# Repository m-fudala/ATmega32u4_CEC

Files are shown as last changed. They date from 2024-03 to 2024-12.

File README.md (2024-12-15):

# ATmega32U4 CEC device
## Software
HDMI CEC protocol has been programmed using GPIO pins and timers.\
Full protocol feature set is to be done (address setting, commands etc.).&nbsp;&nbsp;

Sample message sent and received:

Message captured

## Hardware
PCB has been designed as a pass-through between media player and a TV. Arduino Pro Micro is used as the brains of the device.
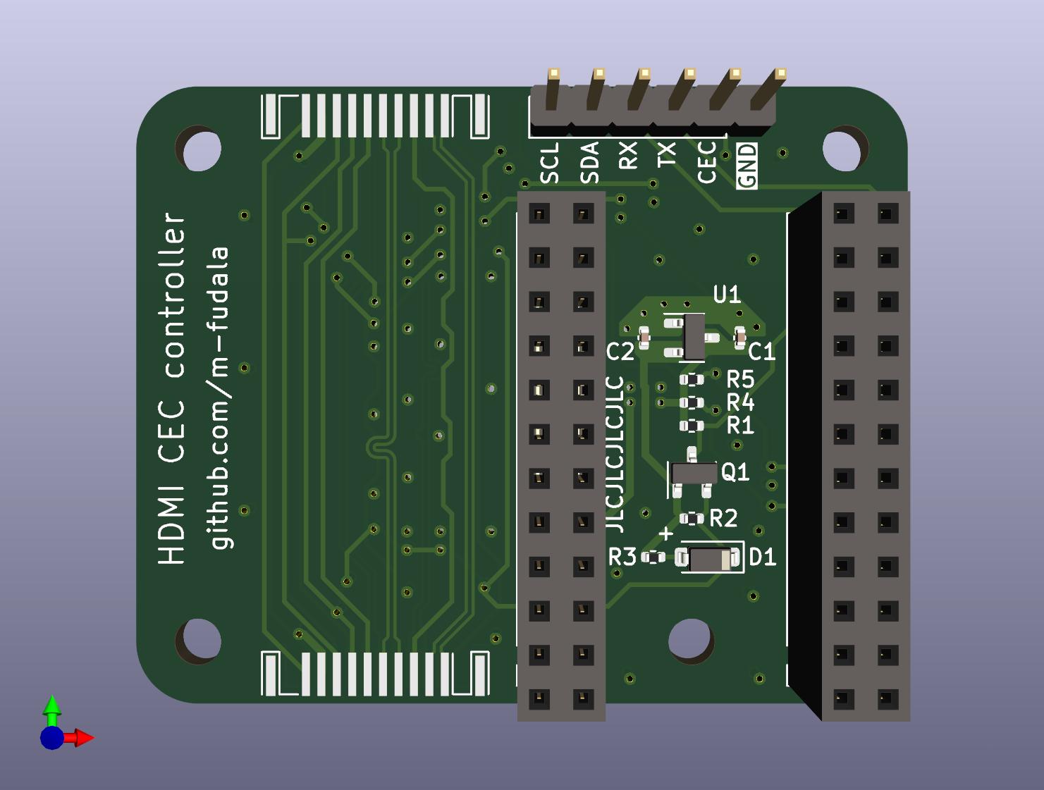
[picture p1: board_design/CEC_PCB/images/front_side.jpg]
Front side of the PCB
\
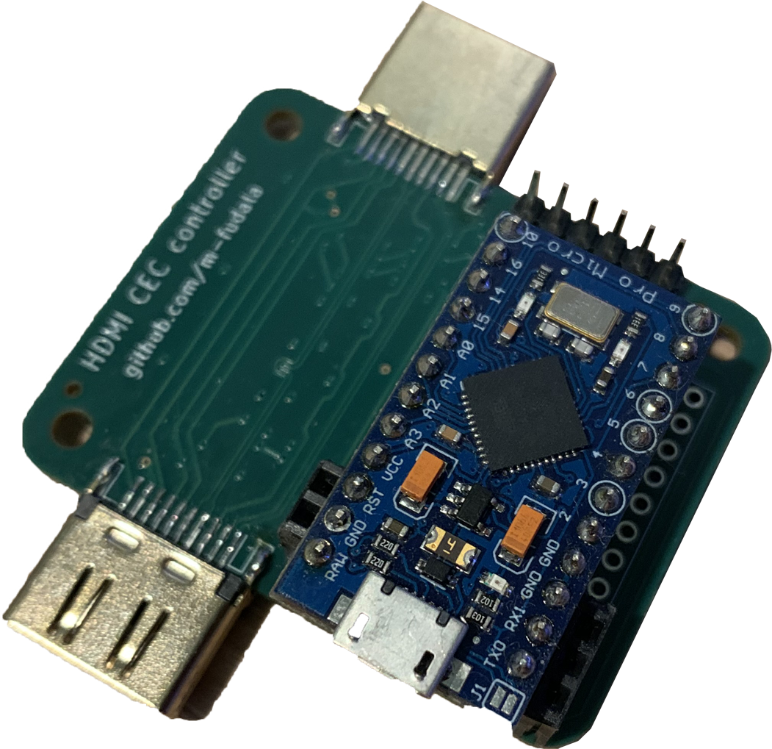
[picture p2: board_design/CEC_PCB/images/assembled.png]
Assembled PCB


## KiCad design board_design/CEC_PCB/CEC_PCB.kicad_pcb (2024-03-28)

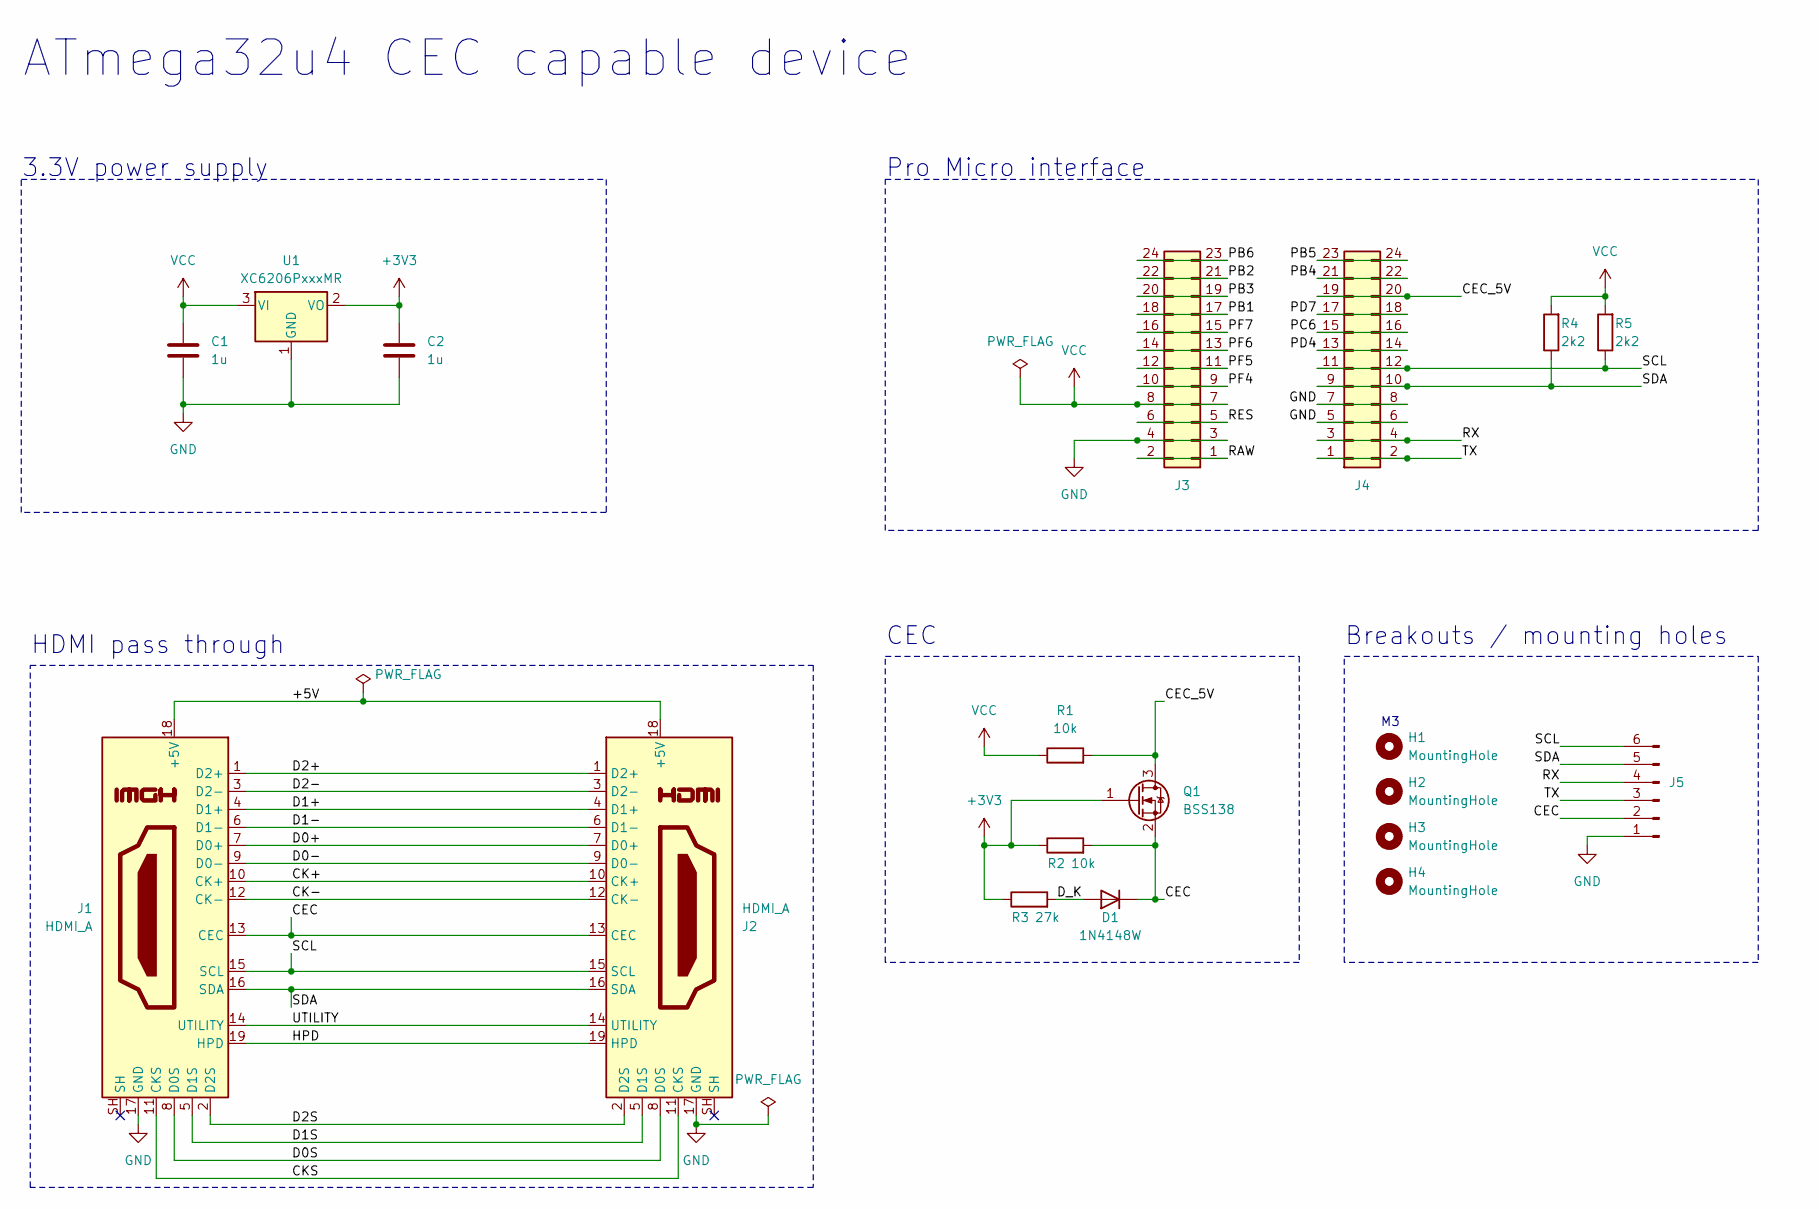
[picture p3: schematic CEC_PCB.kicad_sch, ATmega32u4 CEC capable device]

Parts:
C1, C2: 1u; C_0402_1005Metric
D1: 1N4148W; D_SOD-123
H1, H2, H3, H4: MountingHole; MountingHole_3mm
J1, J2: HDMI_A; HDMI_A_Contact_Technology_HDMI-19APL2_Horizontal
J3, J4: Conn_02x12_Odd_Even; PinSocket_2x12_P2.54mm_Vertical
J5: Conn_01x06_Pin; PinHeader_1x06_P2.54mm_Vertical
Q1: BSS138; SOT-23
R1, R2: 10k; R_0402_1005Metric
R3: 27k; R_0402_1005Metric
R4, R5: 2k2; R_0402_1005Metric
U1: XC6206PxxxMR; SOT-23-3

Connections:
+3V3: C2.1, Q1.1 (G), R2.1, R3.1, U1.2 (VO)
/+5V: J1.18 (+5V), J2.18 (+5V)
/CEC: D1.1 (K), J1.13 (CEC), J2.13 (CEC), J5.2, Q1.2 (S), R2.2
/CEC_5V: J3.19, J3.20, Q1.3 (D), R1.2
/CK+: J1.10 (CK+), J2.10 (CK+)
/CK-: J1.12 (CK-), J2.12 (CK-)
/CKS: J1.11 (CKS), J2.11 (CKS)
/D0+: J1.7 (D0+), J2.7 (D0+)
/D0-: J1.9 (D0-), J2.9 (D0-)
/D0S: J1.8 (D0S), J2.8 (D0S)
/D1+: J1.4 (D1+), J2.4 (D1+)
/D1-: J1.6 (D1-), J2.6 (D1-)
/D1S: J1.5 (D1S), J2.5 (D1S)
/D2+: J1.1 (D2+), J2.1 (D2+)
/D2-: J1.3 (D2-), J2.3 (D2-)
/D2S: J1.2 (D2S), J2.2 (D2S)
/D_K: D1.2 (A), R3.2
/HPD: J1.19 (HPD), J2.19 (HPD)
/PB1: J4.17, J4.18
/PB2: J4.21, J4.22
/PB3: J4.19, J4.20
/PB4: J3.21, J3.22
/PB5: J3.23, J3.24
/PB6: J4.23, J4.24
/PC6: J3.15, J3.16
/PD4: J3.13, J3.14
/PD7: J3.17, J3.18
/PF4: J4.9, J4.10
/PF5: J4.11, J4.12
/PF6: J4.13, J4.14
/PF7: J4.15, J4.16
/RAW: J4.1, J4.2
/RES: J4.5, J4.6
/RX: J3.3, J3.4, J5.4
/SCL: J1.15 (SCL), J2.15 (SCL), J3.11, J3.12, J5.6, R5.1
/SDA: J1.16 (SDA), J2.16 (SDA), J3.9, J3.10, J5.5, R4.1
/TX: J3.1, J3.2, J5.3
/UTILITY: J1.14 (UTILITY), J2.14 (UTILITY)
GND: C1.2, C2.2, J1.17 (GND), J2.17 (GND), J3.5, J3.6, J3.7, J3.8, J4.3, J4.4, J5.1, U1.1 (GND)
VCC: C1.1, J4.7, J4.8, R1.1, R4.2, R5.2, U1.3 (VI)

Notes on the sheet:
Breakouts / mounting holes
CEC
HDMI pass through
Pro Micro interface
ATmega32u4 CEC capable device
3.3V power supply

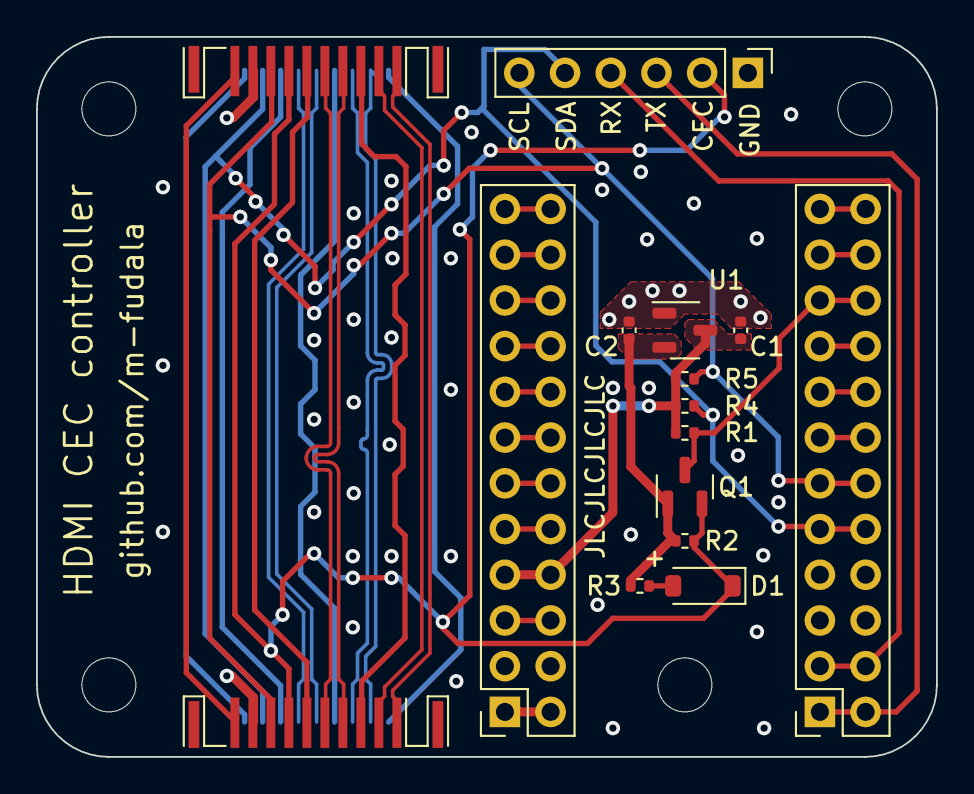
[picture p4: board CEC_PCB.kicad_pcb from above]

Board: 4 copper layers, 50.0 x 40.0 mm, 19 parts (0 on the bottom side), 40 nets.

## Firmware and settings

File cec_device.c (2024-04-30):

/*
    Program turning an ATmega32u4 microcontroller into a HDMI Consumer
    Electronics Control capable device.

    https://github.com/m-fudala
*/

#include <stdio.h>
#include <util/delay.h>
#include "ATmega32u4_libraries/uart_library/uart.h"
#include "ATmega32u4_libraries/external_interrupt_library/external_interrupt.h"
#include "ATmega32u4_libraries/gpio_library/gpio.h"
#include "serial_commands.h"
#include "hdmi_cec.h"
#include "cec_commands.h"


int main()
{
    USBCON = 0;

    uart_start(BAUD_250K);

    unsigned char uart_rx_buffer[8];

    cec_init();

    unsigned char message_to_be_sent = 0;

    while (1) {
        if (message_to_be_sent &&
                (Rx.status.bus_idle_overflow || (TCNT3 > (5 * BIT_TIME)))) {
            message_to_be_sent = 0;

            // buffer used to send debug with transmitted messages
            // 3 characters at the start, 3 characters for every byte plus
            // a space and termination at the end
            unsigned char buffer_tx[3 + Tx.no_of_bytes * 3 + 3];

            sprintf(buffer_tx, "TX:");

            for (unsigned char i = 0; i < Tx.no_of_bytes; ++i) {
                sprintf(buffer_tx, "%s %02X", buffer_tx, Tx.bytes[i]);
            }

            sprintf(buffer_tx, "%s\r\n", buffer_tx);

            uart_send(buffer_tx, 3 + Tx.no_of_bytes * 3 + 3 - 1);
            
            send_start();
        }

        if (Rx.status.message_received) {
            Rx.status.message_received = 0;

            CEC_command received_command = {
                .header = Rx.buffer[0],
                .opcode = Rx.buffer[1]
            };

            if (((received_command.header & 0xF) == cec_address)
                    && (Rx.status.bytes_read > 1)) {

                // buffer used to send debug with received messages
                // 3 characters at the start, 3 characters for every byte plus
                // a space and termination at the end
                unsigned char buffer_rx[3 + Rx.status.bytes_read * 3 + 3];

                sprintf(buffer_rx, "RX:");

                for (unsigned char i = 0; i < Rx.status.bytes_read; ++i) {
                    sprintf(buffer_rx, "%s %02X", buffer_rx, Rx.buffer[i]);
                }

                sprintf(buffer_rx, "%s\r\n", buffer_rx);

                uart_send(buffer_rx, 3 + Rx.status.bytes_read * 3 + 3 - 1);
            }

            switch (received_command.opcode) {
                case GIVE_DECK_STATUS: {
                    // send Play status
                    Tx.bytes =
                        (unsigned char[3]){(cec_address << 4) | 0,
                            DECK_STATUS, 0x20};
                    Tx.no_of_bytes = 3;

                    message_to_be_sent = 1;

                    break;
                }

                case GIVE_OSD_NAME: {
                    // set 'TV PC' as OSD name
                    Tx.bytes =
                        (unsigned char[7]){(cec_address << 4) | 0,
                            SET_OSD_NAME, 'T', 'V', ' ', 'P', 'C'};
                    Tx.no_of_bytes = 7;

                    message_to_be_sent = 1;

                    break;
                }

                case GIVE_PHYSICAL_ADDRESS: {
                    // respond with static address
                    Tx.bytes =
                        (unsigned char[5]){(cec_address << 4) | 0,
                            REPORT_PHYSICAL_ADDRESS, 0x10, 0x00, 0x04};
                    Tx.no_of_bytes = 5;

                    message_to_be_sent = 1;

                    break;
                }

                case VENDOR_COMMAND: {
                    switch (Rx.buffer[2]) {
                        case 0x01: {
                            Tx.bytes =
                                (unsigned char[4]){(cec_address << 4) | 0,
                                    VENDOR_COMMAND, 0x02, 0x05};
                            Tx.no_of_bytes = 4;

                            message_to_be_sent = 1;

                            break;
                        }

                        case 0x0B: {
                            Tx.bytes =
                                (unsigned char[4]){(cec_address << 4) | 0,
                                    VENDOR_COMMAND, 0x0C, 0x01};
                            Tx.no_of_bytes = 4;

                            message_to_be_sent = 1;

                            break;
                        }
                    }

                    break;
                }

                case GIVE_DEVICE_VENDOR_ID: {
                    // respond with some ID
                    Tx.bytes =
                        (unsigned char[5]){(cec_address << 4) | 0xF,
                            DEVICE_VENDOR_ID, 0x00, 0xE0, 0x91};
                    Tx.no_of_bytes = 5;

                    message_to_be_sent = 1;

                    break;
                }

                case GIVE_DEVICE_POWER_STATUS: {
                    // respond with status On
                    Tx.bytes =
                        (unsigned char[3]){(cec_address << 4) | 0,
                            REPORT_POWER_STATUS, 0x00};
                    Tx.no_of_bytes = 3;

                    message_to_be_sent = 1;

                    break;
                }

                case GET_CEC_VERSION: {
                    // respond with CEC version
                    Tx.bytes =
                        (unsigned char[3]){(cec_address << 4) | 0,
                            CEC_VERSION, 0x04};
                    Tx.no_of_bytes = 3;

                    message_to_be_sent = 1;

                    break;
                }

                default: {
                    if (((received_command.header & 0xF) == cec_address)
                        && (Rx.status.bytes_read > 1)) {
                        // respond with Feature Abort
                        Tx.bytes =
                            (unsigned char[4]){(cec_address << 4) | 0,
                                FEATURE_ABORT, received_command.opcode, 0x00};
                        Tx.no_of_bytes = 4;

                        message_to_be_sent = 1;

                        break;
                    }
                }
            }
        }

        if (Rx.send_debug) {
            uart_send((unsigned char[1]){Rx.send_debug}, 1);

            Rx.send_debug = 0;
        }

        if (Tx.send_debug) {
            uart_send((unsigned char[1]){Tx.send_debug}, 1);

            Tx.send_debug = 0;
        }

        if (!check_message_readiness()) {
            uart_read(uart_rx_buffer, 8);
            unsigned char selected_command = 0;

            for (unsigned char command_no = 0; command_no < NO_OF_COMMANDS;
                    ++command_no) {
                unsigned char character_hits = 0;

                for (unsigned char character = 0;
                        character < commands[command_no].command_len;
                        ++ character) {
                    if (commands[command_no].command_str[character] ==
                            uart_rx_buffer[character]) {
                        ++character_hits;
                    }
                }

                if (character_hits == commands[command_no].command_len) {
                    selected_command = command_no + 1;
                }
            }

            switch (selected_command) {
                case INV_COMMAND: {
                    unsigned char send_nok[11] = "Inv comm\r\n";
                    uart_send(send_nok,
                            sizeof(send_nok) / sizeof(unsigned char) - 1);

                    break;
                }

                case STB: {
                    unsigned char res[] = "Switching to standby\r\n";

                    uart_send(res, sizeof(res) / sizeof(unsigned char) - 1);

                    // send Standby to TV
                    Tx.bytes =
                        (unsigned char[4]){(cec_address << 4) | 0xF, STANDBY};
                    Tx.no_of_bytes = 2;

                    message_to_be_sent = 1;

                    break;
                }

                case IV: {
                    unsigned char res[] = "Turning image ON\r\n";

                    uart_send(res, sizeof(res) / sizeof(unsigned char) - 1);

                    // send Image View On
                    Tx.bytes =
                        (unsigned char[4]){(cec_address << 4) | 0,
                        IMAGE_VIEW_ON};
                    Tx.no_of_bytes = 2;

                    message_to_be_sent = 1;

                    break;
                }

                case AS: {
                    unsigned char res[] = "Changing source\r\n";

                    uart_send(res, sizeof(res) / sizeof(unsigned char) - 1);

                    // send Active Source
                    // send static address
                    Tx.bytes =
                        (unsigned char[4]){(cec_address << 4) | 0xF,
                            ACTIVE_SOURCE, 0x10, 0x00};
                    Tx.no_of_bytes = 4;

                    message_to_be_sent = 1;

                    break;
                }

                case VU: {
                    unsigned char res[] = "Volume up\r\n";

                    uart_send(res, sizeof(res) / sizeof(unsigned char) - 1);

                    // send User Control Volume Up
                    Tx.bytes =
                        (unsigned char[3]){(cec_address << 4) | 0,
                            USER_CONTROL_PRESSED, VOLUME_UP};
                    Tx.no_of_bytes = 3;

                    message_to_be_sent = 1;

                    break;
                }

                case VD: {
                    unsigned char res[] = "Volume down\r\n";

                    uart_send(res, sizeof(res) / sizeof(unsigned char) - 1);

                    // send User Control Volume Down
                    Tx.bytes =
                        (unsigned char[3]){(cec_address << 4) | 0,
                            USER_CONTROL_PRESSED, VOLUME_DOWN};
                    Tx.no_of_bytes = 3;

                    message_to_be_sent = 1;

                    break;
                }

                case MT: {
                    unsigned char res[] = "Muting\r\n";

                    uart_send(res, sizeof(res) / sizeof(unsigned char) - 1);

                    // send User Control Mute
                    Tx.bytes =
                        (unsigned char[3]){(cec_address << 4) | 0,
                            USER_CONTROL_PRESSED, MUTE};
                    Tx.no_of_bytes = 3;

                    message_to_be_sent = 1;

                    break;
                }

                case OSD: {
                    unsigned char res[] = "Setting OSD string\r\n";

                    uart_send(res, sizeof(res) / sizeof(unsigned char) - 1);

                    // send Set OSD String
                    Tx.bytes =
                        (unsigned char[7]){(cec_address << 4) | 0,
                            SET_OSD_STRING, 0x0, 'T', 'E', 'S', 'T'};
                    Tx.no_of_bytes = 7;

                    message_to_be_sent = 1;

                    break;
                }

                case CV: {
                    unsigned char res[] = "Getting CEC version\r\n";

                    uart_send(res, sizeof(res) / sizeof(unsigned char) - 1);

                    // send Get CEC Version
                    Tx.bytes =
                        (unsigned char[2]){(cec_address << 4) | 0,
                            GET_CEC_VERSION};
                    Tx.no_of_bytes = 2;

                    message_to_be_sent = 1;

                    break;
                }

                case SND: {
                    unsigned char res[] = "SND\r\n";

                    uart_send(res, sizeof(res) / sizeof(unsigned char) - 1);

                    // send 
                    Tx.bytes =
                        (unsigned char[3]){(cec_address << 4) | 0,
                            0x89, 0x01};
                    Tx.no_of_bytes = 3;

                    message_to_be_sent = 1;

                    break;
                }
            }
        }
    }

    return 0;
}

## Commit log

2024-02-20 File prototypes
2024-02-29 Button used for debugging purposes
2024-03-01 Bus status as bit field Interrupt 6 added to bus Option to set device as initiator or follower
2024-03-01 Sending multiple bytes Function for inserting EOM
2024-03-01 Prototype of receiver
2024-03-06 Only setting timer interrupts when needed TX and IO debugs Waiting for ACK on TX side Prototype of sending ACK on RX
2024-03-19 Fix for follower not being established after sending Fixed some issues in board's design
2024-03-19 Prototype PCB design files .gitignore updated with KiCad backup files
    [CEC_PCB.kicad_pcb, CEC_PCB.kicad_sch]
2024-03-19 HDMI connectors Board stackup and constraints Pre-defiened sizes Schematic prototype
    [CEC_PCB.kicad_pcb, CEC_PCB.kicad_sch]
2024-03-19 LDO for 3.3V power CEC level shifting I2C pull-up resistors
    [CEC_PCB.kicad_sch]
2024-03-19 Broke out Pro Micro pins using a connector with two rows Level shifter between CEC pins Mounting holes and debug pins PCB outline defined Crude component placement Copper pours on GND planes
    [CEC_PCB.kicad_pcb, CEC_PCB.kicad_sch]
2024-03-20 Labels for nets in the schematic Board size change Parts placement change Basic routing
    [CEC_PCB.kicad_pcb, CEC_PCB.kicad_sch]
2024-03-20 Track routing done
    [CEC_PCB.kicad_pcb]
2024-03-21 Optimizations and silkscreen annotations
    [CEC_PCB.kicad_pcb]
2024-03-21 Changed VDO capacitors to 1uF Some routing changes Ground vias throughout the PCB Some optimizations
    [CEC_PCB.kicad_pcb, CEC_PCB.kicad_sch]
2024-03-28 Final PCB touches
    [CEC_PCB.kicad_pcb, CEC_PCB.kicad_sch]
2024-04-10 Prototype of responding to messages
2024-04-15 Reacting to opcodes from cec_commands.h Sending only directly addressed messages to UART Sending Active Source from UART command TX workaround: waiting for ACK only when directly addressing
    [cec_device.c]
2024-04-15 Fixed sending every time a message is received Responding to Give OSD Name command
    [cec_device.c]
2024-04-22 Sending received bytes as characters on UART Use of defines Fixed TX bug when sending for the first time
    [cec_device.c]
2024-04-24 Usage of Timer 3 to count bus idle time Waiting automatically for 5 bit times of idle bus
2024-04-30 Fixed Device Vendor ID command New commands Sending Feature Abort when opcode is not recognized
    [cec_device.c]
